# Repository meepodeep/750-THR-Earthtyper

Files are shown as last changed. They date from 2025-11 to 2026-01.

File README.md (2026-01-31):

# 750-THR-Earthtyper
The 1000-THR Earthmover shrunk down to a keyboard size!




earthtyper render

render







# Why does this exist
I wanted to make an ultrakill themed keyboard, so i did!
# How to software
 1. DO BEFORE BUILD ITS EASIER I THINK
 2. Download QMK Toolbox and flash earthtyper via.hex onto the teensy by plugging it in, hitting the boot button and flashing. 
# How to build
1. solder the keyswitches onto the front of pcb using the laser cut Keyboard plate.svg , along with the teensy 2.0 and diodes on the back
2. Attach led strips to the inside of the case



4. Mask, engrave and cut the rear plate out of acrylic benjamin back.svg

5. Paint the engraved back plate
  
6. mount the keyboard pcb with m2 screws


7. cut the internal usb cable short on the mini b end

8. resolder the wire together so it doesnt have to coil and the usb c can still reach the outside
  
10. Use whatever method of securing the usb c cable to the pcb so that it aligns with the hole in the case

11. plug the mini b cable into the teensy.
 
12. mount the front peice with m3 screws while having the back plate on




#BOM
|Item |Price  |Quantity |Use |Link |
|---|---|---|---|---|
|KTT Kang White V3 |$24.89 |1x 90pcs |Keyswitches |https://www.aliexpress.us/item/3256807301426125.html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 |
|WS2812B 5v 2m 30 leds |$5.16  |1x 2m 30 ip30|backlight |https://www.aliexpress.us/item/3256804103077154.html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 |
|Teensy 2.0 |$9.18  |1X |mcu |https://www.aliexpress.us/item/3256803067426595.html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 |
|usb adapter 20cm V8F-V3ST |$2.24  |1x |adapt the usb |https://www.aliexpress.us/item/3256805661411472.html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 |
|transparent keycaps |$18.82 |1x |cap keys |https://www.aliexpress.us/item/3256809158263730.html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 |
|1/8th in acrylic sheet |$15 |1x |be the backplate and plate|my makerspace! |
|m2 screws 4mm |$2.24  |1x |mount the pcb |https://www.aliexpress.us/item/3256806812715286.html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|
|m3 screws |$0 |gottem |gottem |yo tengo |
|pcbs |$33.74 |5x |be a pcb |jlcpcb |
|Diodes |$2.38  |2x |be diodes |https://www.aliexpress.us/item/3256806058794623.html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 |
|Stablizers |$10  | |stablize keys |https://mechanicalkeyboards.com/products/gateron-v2-stabilizers-plate-mount-clip-in-tkl-kit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 |
|Total without tax or shipping|$117.14| | | |
|Total |$121.32| | | |

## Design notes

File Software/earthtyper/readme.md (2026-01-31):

# earthtyper

earthtyper

*A short description of the keyboard/project*

* Keyboard Maintainer: [meepodeep](https://github.com/meepodeep)
* Hardware Supported: *The PCBs, controllers supported*
* Hardware Availability: *Links to where you can find this hardware*

Make example for this keyboard (after setting up your build environment):

    make earthtyper:default

Flashing example for this keyboard:

    make earthtyper:default:flash

See the [build environment setup](https://docs.qmk.fm/#/getting_started_build_tools) and the [make instructions](https://docs.qmk.fm/#/getting_started_make_guide) for more information. Brand new to QMK? Start with our [Complete Newbs Guide](https://docs.qmk.fm/#/newbs).

## Bootloader

Enter the bootloader in 3 ways:

* **Bootmagic reset**: Hold down the key at (0,0) in the matrix (usually the top left key or Escape) and plug in the keyboard
* **Physical reset button**: Briefly press the button on the back of the PCB - some may have pads you must short instead
* **Keycode in layout**: Press the key mapped to `QK_BOOT` if it is available

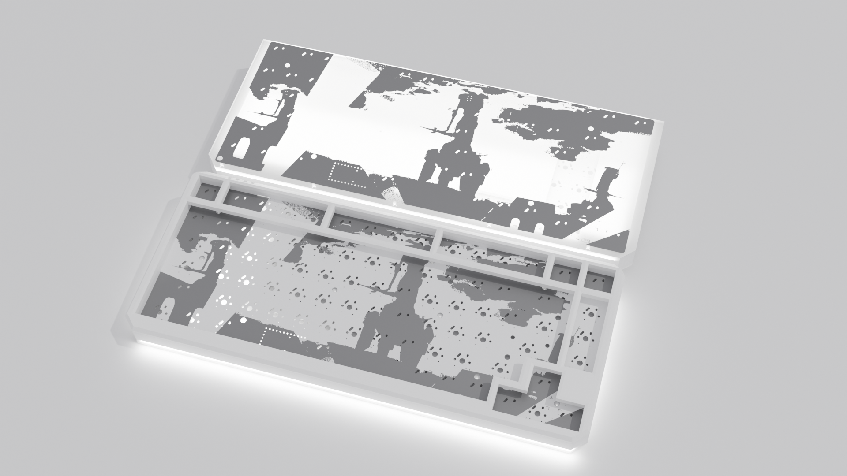
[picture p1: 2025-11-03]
render.png

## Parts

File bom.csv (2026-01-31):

Item | Price | Quantity | Use | Link
KTT Kang White V3 | $24.89 | 1x 90pcs | Keyswitches | https://www.aliexpress.us/item/3256807301426125.html?mp=1
WS2812B 5v 2m 30 leds | $5.16 | 1x 2m 30 ip30 | backlight | https://www.aliexpress.us/item/3256804103077154.html?mp=1
Teensy 2.0 | $9.18 | 1X | mcu | https://www.aliexpress.us/item/3256803067426595.html
usb adapter 20cm V8F-V3ST | $2.24 | 1x | adapt the usb | https://www.aliexpress.us/item/3256805661411472.html?mp=1
transparent keycaps | $18.82 | 1x | cap keys | https://www.aliexpress.us/item/3256809158263730.html?mp=1
1/8th in acrylic sheet | $15 | 1x | be the backplate and plate | my makerspace!
m2 screws 4mm | $2.24 | 1x | mount the pcb | https://www.aliexpress.us/item/3256806812715286.html?curPageLogUid=lCJAop0qt41n
m3 screws | $0 | gottem | gottem | yo tengo
pcbs | $33.74 | 5x | be a pcb | jlcpcb
Diodes | $2.38 | 2x | be diodes | https://www.aliexpress.us/item/3256806058794623.html?curPageLogUid=29HuQ5YR0viZ
Stablizers | $10.00 |  | stablize keys | https://mechanicalkeyboards.com/products/gateron-v2-stabilizers-plate-mount-clip-in-tkl-kit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
Total without tax or shipping | $123.65
Total | $121.32

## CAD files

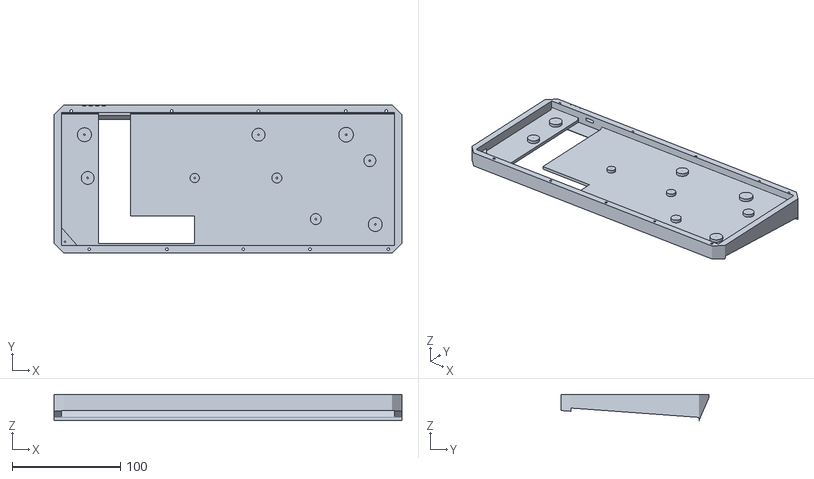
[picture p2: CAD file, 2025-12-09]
Cad files/Bottom whole.stl
321.9 x 137.2 x 24.3

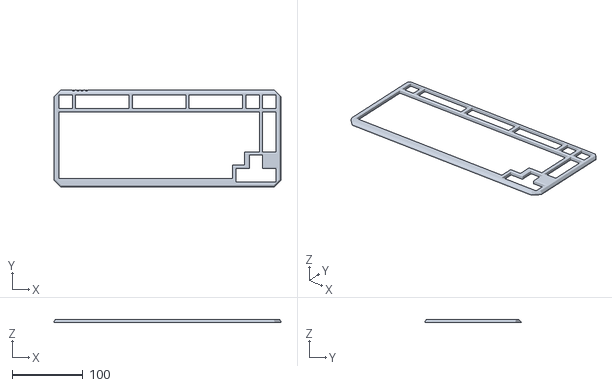
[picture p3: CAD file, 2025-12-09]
Cad files/top whole.stl
321.9 x 137.2 x 4.90

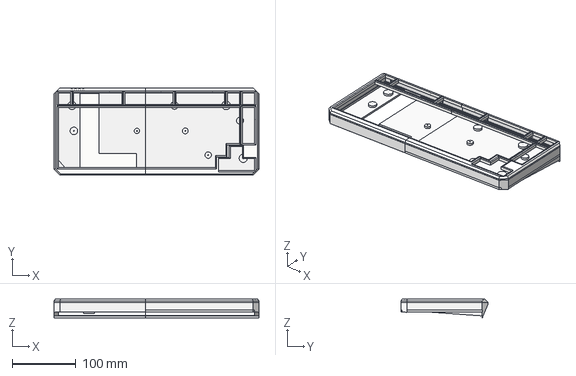
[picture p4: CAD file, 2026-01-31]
Cad files/750-THR-Earthtyper.step
321.9 x 137.2 x 29.3 mm

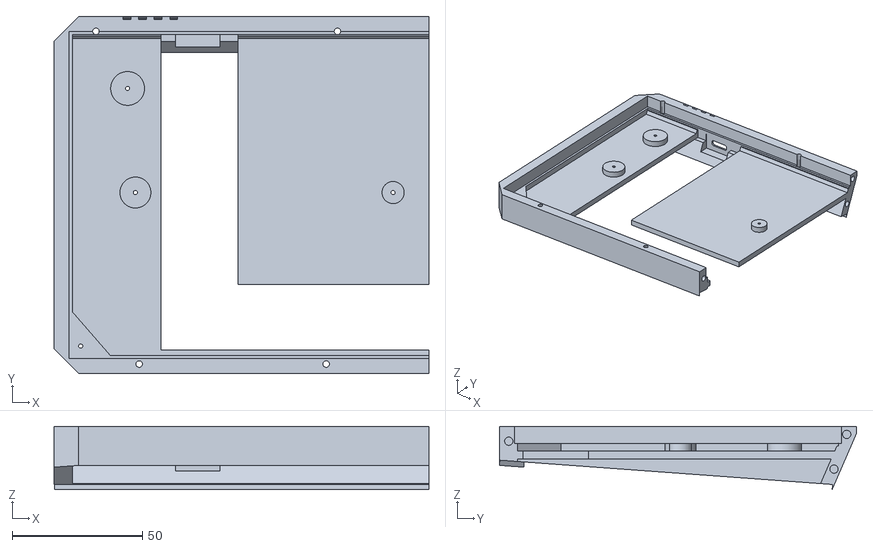
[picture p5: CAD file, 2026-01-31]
Cad files/Left bottom.stl
143.9 x 137.2 x 24.3

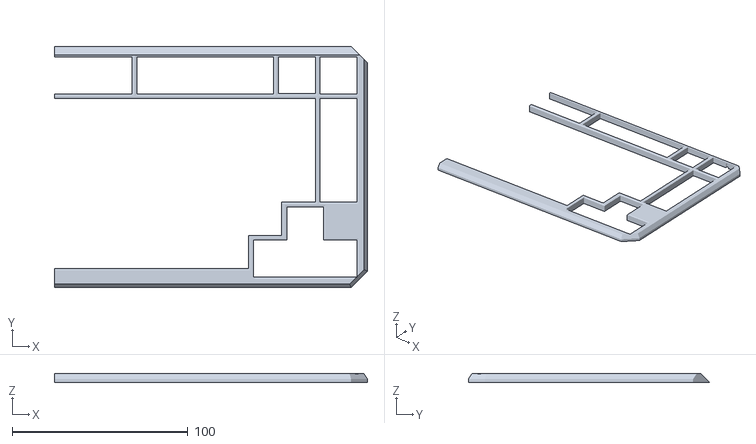
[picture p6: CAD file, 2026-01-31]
Cad files/Right top.stl
178.0 x 137.2 x 4.90

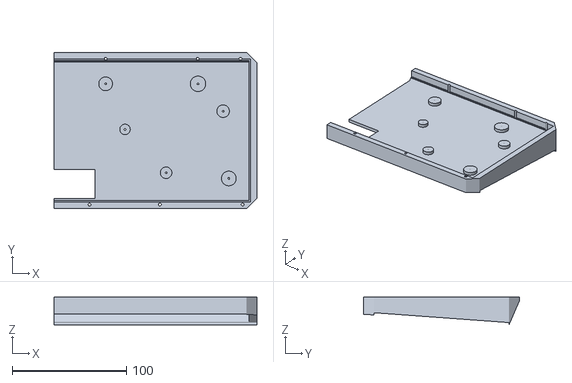
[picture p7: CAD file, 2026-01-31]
Cad files/Right bottom.stl
178.0 x 137.2 x 24.3

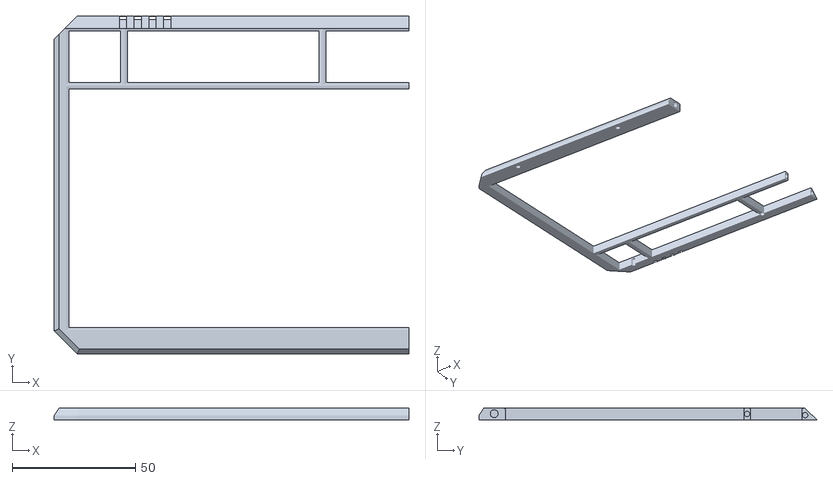
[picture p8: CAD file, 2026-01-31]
Cad files/Left top.stl
143.9 x 137.2 x 4.90

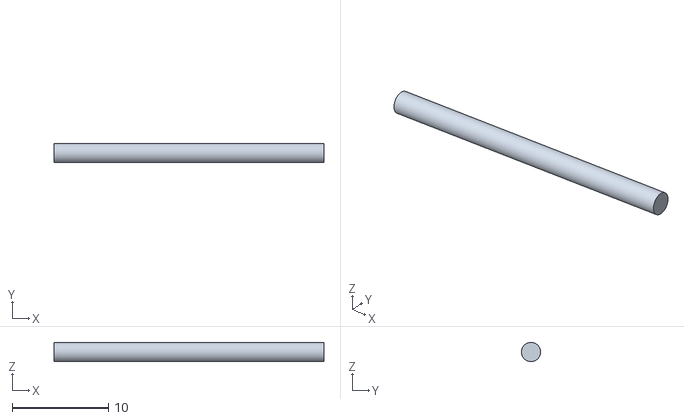
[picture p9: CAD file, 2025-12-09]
Cad files/pin.stl
28.0 x 2.00 x 2.00

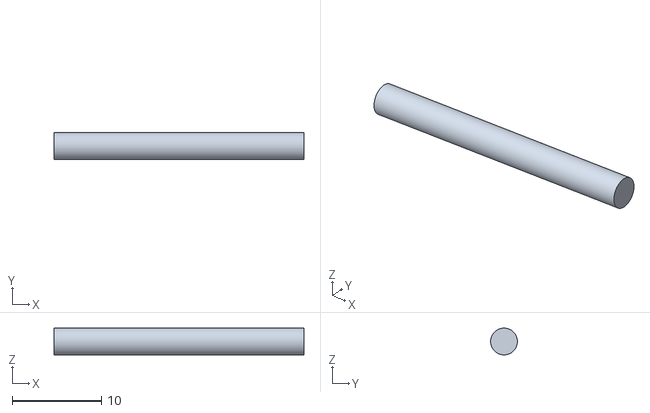
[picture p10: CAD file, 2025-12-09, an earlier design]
Cad files/pin (2).stl
28.0 x 3.00 x 3.00

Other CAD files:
Cad files/main base.stl
Cad files/Top Plate.stl
Cad files/pin (3).stl
Cad files/pin (4).stl
Cad files/pin (5).stl
Cad files/pin (1).stl

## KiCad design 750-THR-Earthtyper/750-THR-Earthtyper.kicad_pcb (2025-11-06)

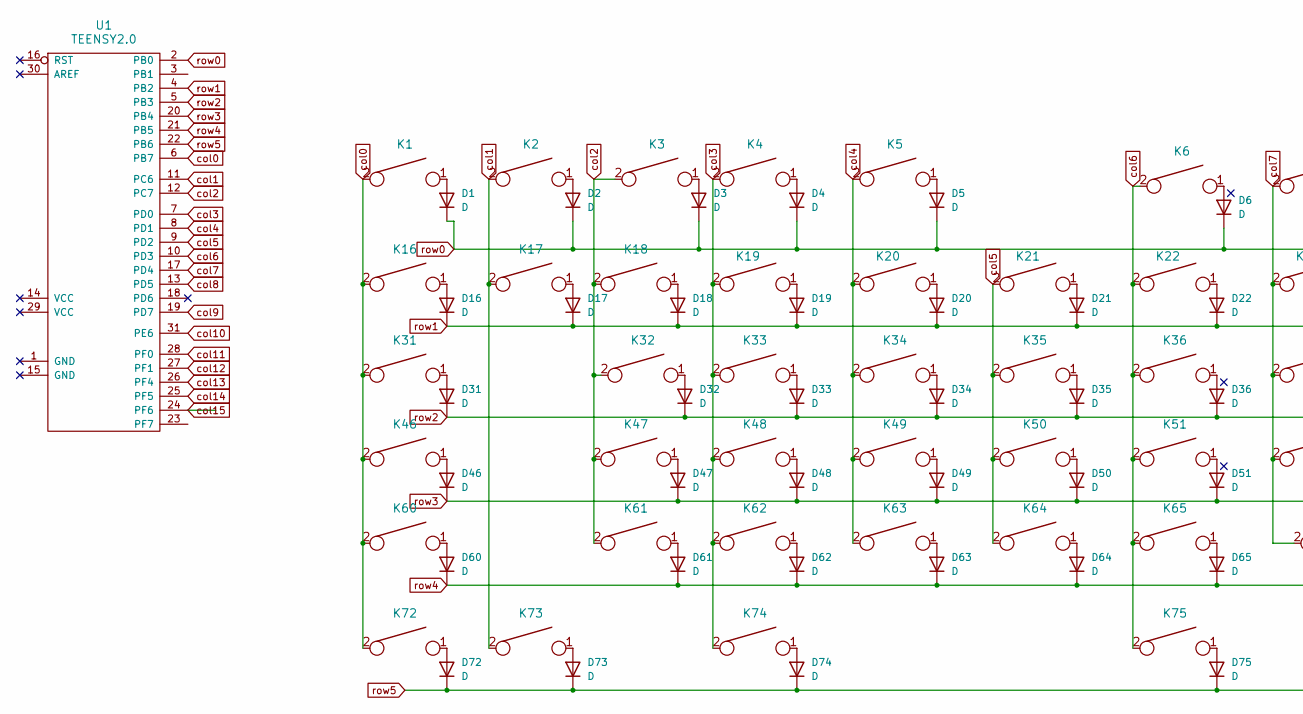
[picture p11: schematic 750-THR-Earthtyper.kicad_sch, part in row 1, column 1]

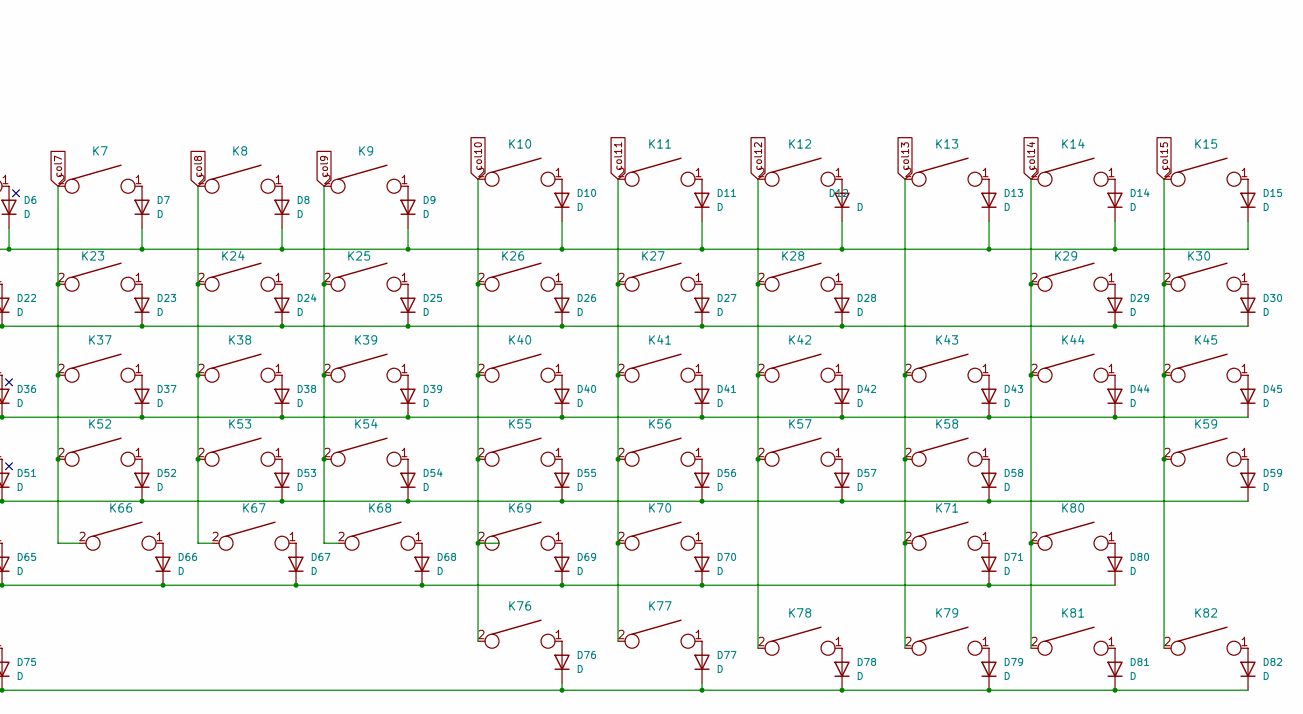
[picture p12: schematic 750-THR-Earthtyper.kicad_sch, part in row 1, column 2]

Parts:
D1, D2, D3, D4, D5, D6, D7, D8, D9, D10, D11, D12, D13, D14, D15, D16, D17, D18, D19, D20, D21, D22, D23, D24, D25, D26, D27, D28, D29, D30, D31, D32, D33, D34, D35, D36, D37, D38, D39, D40, D41, D42, D43, D44, D45, D46, D47, D48, D49, D50, D51, D52, D53, D54, D55, D56, D57, D58, D59, D60, D61, D62, D63, D64, D65, D66, D67, D68, D69, D70, D71, D72, D73, D74, D75, D76, D77, D78, D79, D80, D81, D82: D; D_SOD123_axial
K1, K2, K3, K4, K5, K6, K7, K8, K9, K10, K11, K12, K13, K14, K15, K16, K17, K18, K19, K20, K21, K22, K23, K24, K25, K26, K27, K28, K30, K32, K33, K34, K35, K36, K37, K38, K39, K40, K41, K42, K43, K45, K47, K48, K49, K50, K51, K52, K53, K54, K55, K56, K57, K59, K61, K62, K63, K64, K65, K66, K67, K68, K69, K70, K71, K72, K73, K74, K75, K76, K77, K78, K79, K80, K81, K82: KEYSW; Mx_Alps_100
K29: KEYSW; Mx_Alps_200
K31, K44: KEYSW; Mx_Alps_150
K46: KEYSW; Mx_Alps_175
K58, K60: KEYSW; Mx_Alps_225
U1: TEENSY2.0; Teensy_20

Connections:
unnamed: D1.2 (A), K1.1
unnamed: D2.2 (A), K2.1
unnamed: D3.2 (A), K3.1
unnamed: D4.2 (A), K4.1
unnamed: D5.2 (A), K5.1
unnamed: D6.2 (A), K6.1
unnamed: D7.2 (A), K7.1
unnamed: D8.2 (A), K8.1
unnamed: D9.2 (A), K9.1
unnamed: D10.2 (A), K10.1
unnamed: D11.2 (A), K11.1
unnamed: D12.2 (A), K12.1
unnamed: D13.2 (A), K13.1
unnamed: D14.2 (A), K14.1
unnamed: D15.2 (A), K15.1
unnamed: D16.2 (A), K16.1
unnamed: D17.2 (A), K17.1
unnamed: D18.2 (A), K18.1
unnamed: D19.2 (A), K19.1
unnamed: D20.2 (A), K20.1
unnamed: D21.2 (A), K21.1
unnamed: D22.2 (A), K22.1
unnamed: D23.2 (A), K23.1
unnamed: D24.2 (A), K24.1
unnamed: D25.2 (A), K25.1
unnamed: D26.2 (A), K26.1
unnamed: D27.2 (A), K27.1
unnamed: D28.2 (A), K28.1
unnamed: D29.2 (A), K29.1
unnamed: D30.2 (A), K30.1
unnamed: D31.2 (A), K31.1
unnamed: D32.2 (A), K32.1
unnamed: D33.2 (A), K33.1
unnamed: D34.2 (A), K34.1
unnamed: D35.2 (A), K35.1
unnamed: D36.2 (A), K36.1
unnamed: D37.2 (A), K37.1
unnamed: D38.2 (A), K38.1
unnamed: D39.2 (A), K39.1
unnamed: D40.2 (A), K40.1
unnamed: D41.2 (A), K41.1
unnamed: D42.2 (A), K42.1
unnamed: D43.2 (A), K43.1
unnamed: D44.2 (A), K44.1
unnamed: D45.2 (A), K45.1
unnamed: D46.2 (A), K46.1
unnamed: D47.2 (A), K47.1
unnamed: D48.2 (A), K48.1
unnamed: D49.2 (A), K49.1
unnamed: D50.2 (A), K50.1
unnamed: D51.2 (A), K51.1
unnamed: D52.2 (A), K52.1
unnamed: D53.2 (A), K53.1
unnamed: D54.2 (A), K54.1
unnamed: D55.2 (A), K55.1
unnamed: D56.2 (A), K56.1
unnamed: D57.2 (A), K57.1
unnamed: D58.2 (A), K58.1
unnamed: D59.2 (A), K59.1
unnamed: D60.2 (A), K60.1
unnamed: D61.2 (A), K61.1
unnamed: D62.2 (A), K62.1
unnamed: D63.2 (A), K63.1
unnamed: D64.2 (A), K64.1
unnamed: D65.2 (A), K65.1
unnamed: D66.2 (A), K66.1
unnamed: D67.2 (A), K67.1
unnamed: D68.2 (A), K68.1
unnamed: D69.2 (A), K69.1
unnamed: D70.2 (A), K70.1
unnamed: D71.2 (A), K71.1
unnamed: D72.2 (A), K72.1
unnamed: D73.2 (A), K73.1
unnamed: D74.2 (A), K74.1
unnamed: D75.2 (A), K75.1
unnamed: D76.2 (A), K76.1
unnamed: D77.2 (A), K77.1
unnamed: D78.2 (A), K78.1
unnamed: D79.2 (A), K79.1
unnamed: D80.2 (A), K80.1
unnamed: D81.2 (A), K81.1
unnamed: D82.2 (A), K82.1
col0: K1.2, K16.2, K31.2, K46.2, K60.2, K72.2, U1.6 (PB7)
col1: K2.2, K17.2, K73.2, U1.11 (PC6)
col2: K3.2, K18.2, K32.2, K47.2, K61.2, U1.12 (PC7)
col3: K4.2, K19.2, K33.2, K48.2, K62.2, K74.2, U1.7 (PD0)
col4: K5.2, K20.2, K34.2, K49.2, K63.2, U1.8 (PD1)
col5: K21.2, K35.2, K50.2, K64.2, U1.9 (PD2)
col6: K6.2, K22.2, K36.2, K51.2, K65.2, K75.2, U1.10 (PD3)
col7: K7.2, K23.2, K37.2, K52.2, K66.2, U1.17 (PD4)
col8: K8.2, K24.2, K38.2, K53.2, K67.2, U1.13 (PD5)
col9: K9.2, K25.2, K39.2, K54.2, K68.2, U1.19 (PD7)
col10: K10.2, K26.2, K40.2, K55.2, K69.2, K76.2, U1.31 (PE6)
col11: K11.2, K27.2, K41.2, K56.2, K70.2, K77.2, U1.28 (PF0)
col12: K12.2, K28.2, K42.2, K57.2, K78.2, U1.27 (PF1)
col13: K13.2, K43.2, K58.2, K71.2, K79.2, U1.26 (PF4)
col14: K14.2, K29.2, K44.2, K80.2, K81.2, U1.25 (PF5)
col15: K15.2, K30.2, K45.2, K59.2, K82.2, U1.24 (PF6)
row0: D1.1 (K), D2.1 (K), D3.1 (K), D4.1 (K), D5.1 (K), D6.1 (K), D7.1 (K), D8.1 (K), D9.1 (K), D10.1 (K), D11.1 (K), D12.1 (K), D13.1 (K), D14.1 (K), D15.1 (K), U1.2 (PB0)
row1: D16.1 (K), D17.1 (K), D18.1 (K), D19.1 (K), D20.1 (K), D21.1 (K), D22.1 (K), D23.1 (K), D24.1 (K), D25.1 (K), D26.1 (K), D27.1 (K), D28.1 (K), D29.1 (K), D30.1 (K), U1.4 (PB2)
row2: D31.1 (K), D32.1 (K), D33.1 (K), D34.1 (K), D35.1 (K), D36.1 (K), D37.1 (K), D38.1 (K), D39.1 (K), D40.1 (K), D41.1 (K), D42.1 (K), D43.1 (K), D44.1 (K), D45.1 (K), U1.5 (PB3)
row3: D46.1 (K), D47.1 (K), D48.1 (K), D49.1 (K), D50.1 (K), D51.1 (K), D52.1 (K), D53.1 (K), D54.1 (K), D55.1 (K), D56.1 (K), D57.1 (K), D58.1 (K), D59.1 (K), U1.20 (PB4)
row4: D60.1 (K), D61.1 (K), D62.1 (K), D63.1 (K), D64.1 (K), D65.1 (K), D66.1 (K), D67.1 (K), D68.1 (K), D69.1 (K), D70.1 (K), D71.1 (K), D80.1 (K), U1.21 (PB5)
row5: D72.1 (K), D73.1 (K), D74.1 (K), D75.1 (K), D76.1 (K), D77.1 (K), D78.1 (K), D79.1 (K), D81.1 (K), D82.1 (K), U1.22 (PB6)

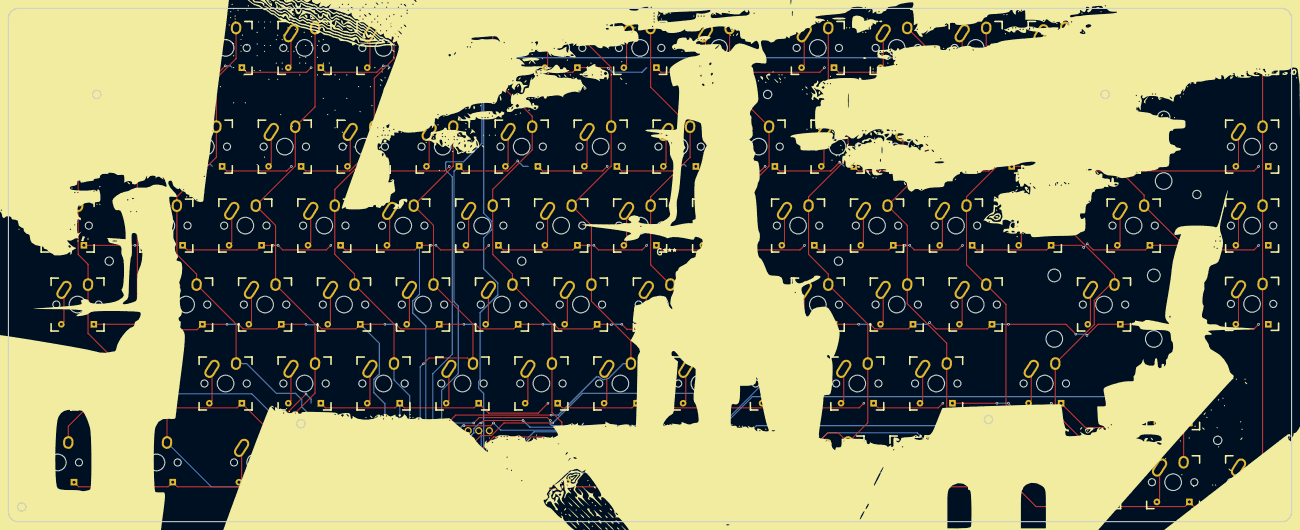
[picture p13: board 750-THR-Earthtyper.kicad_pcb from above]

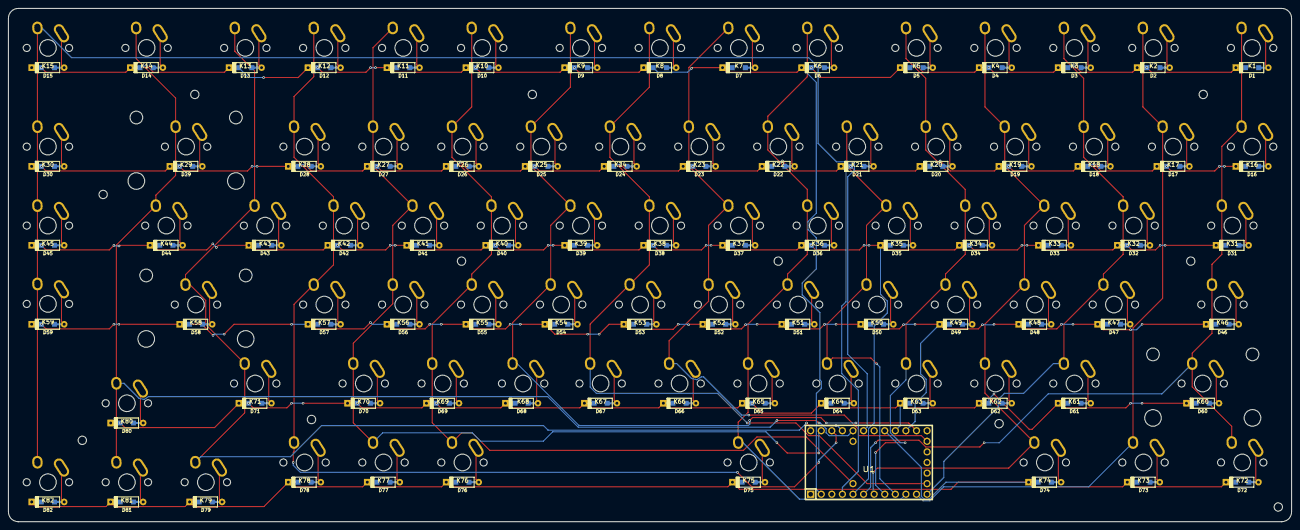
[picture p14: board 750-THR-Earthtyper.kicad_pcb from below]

Board: 2 copper layers, 307.9 x 123.2 mm, 165 parts (83 on the bottom side), 104 nets.

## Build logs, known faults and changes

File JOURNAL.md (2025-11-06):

<!--
  ===================    !!READ THIS NOTICE!!   ====================
  DO NOT edit this file manually. Your changes WILL BE OVERWRITTEN!
  This journal is auto generated and updated by Hack Club Blueprint.
  To edit this file, please edit your journal entries on Blueprint.
  ==================================================================
-->

## 11/2/2025 10 AM - Started designing the pcb  

I decided the layout of the keyboard using Keyboard Layout editor its going to be a 75% (the best %). and started making the schematic and laying out the pcb.



## 11/2/2025 2 PM - Routed the pcb and added design  

Today I routed all the traces of the pcb, cut out the edges, figured out how to do the firmware with qmk and or via, and added the silkscreen image to the front.

## 11/2/2025 6 PM - rerouted everything, and started on the case and renders  

I realized all of the switches were flipped, so i had to flip all of them and reroute the entire pcb. After that I designed a case in fusion and exported it to blender and made some renders.


## 11/3/2025 - added the mount points to the case and made the docs  




Today I made the docs, the bom, finalized the case and also finalized the pcb. This is the hardest part of the project to keep motivation through but atleast im done!  

## 11/4/2025 - I updated the bom and edited the pcb  




This past few days I updated the bom because for some reason one of my cables cost 10 dollars, and I was told the schematic was unreadable (it was) so I started to use net labels.

## 11/6/2025 - fixed drc errors and a schematic error   

Today i fixed the schematic error with a missing column, I also aligned the keys in the schematic on a grid. (i hope this is all of the errors i missed)


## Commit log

2025-11-02 started work
    [750-THR-Earthtyper.kicad_pcb, 750-THR-Earthtyper.kicad_sch]
2025-11-03 added alot of things
    [750-THR-Earthtyper-B_Cu.gbr, 750-THR-Earthtyper-B_Mask.gbr, 750-THR-Earthtyper-B_Paste.gbr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]
2025-11-03 cleaned files
    [Top Plate.stl, main base.stl]
2025-11-03 chagned bom name
    [750-THR-Earthtyper - Sheet1.csv]
2025-11-05 updated the pcb to use net labels (thank you kai)
    [750-THR-Earthtyper.kicad_sch]
2025-11-06 fixed an error with the schematic and organized the schematic
    [750-THR-Earthtyper-B_Cu.gbr, 750-THR-Earthtyper-B_Mask.gbr, 750-THR-Earthtyper-B_Paste.gbr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]
2025-12-09 updated cad model
    [Bottom whole.stl, Left bottom.stl, Left top.stl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]
2025-12-18 Create Keyboard Plate v2.svg
2026-01-15 finished keyboard plate hopefully it works this time
    [Left bottom.stl, Right bottom.stl]
2026-01-31 Updated cad, FREE MEE
    [750-THR-Earthtyper.step, Left bottom.stl, Left top.stl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]
